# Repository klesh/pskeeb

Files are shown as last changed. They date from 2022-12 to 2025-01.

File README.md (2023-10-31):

# Portable Split Keyboard

## Features

- Tenting design - good for RSI symptoms
- Stackable - portable
- 36 keys columnar layout - less movement when typing
- Trackpoint support

## Designs

- [pskeeb1 gateron ks27](pskeeb1_gateron_ks27): Mainly designed for Gateron KS27 low profile switches, Blackpill controller, Diodeless
- [pskeeb2 express](pskeeb2_express): All Kinds of switches, Blackpill controller, Diodeless, 9.2x9.2cm PCB
- [pskeeb3 cherry hotswap](pskeeb3_cherry_hotswap): Cherry MX Switch, Raspberry Pi Pico, Diodeless

## Assembly

#### Trackpoint

1. Follow [this great guide](https://github.com/alonswartz/trackpoint#q-how-do-i-identify-the-trackpoint-pinout) and [this topic](https://geekhack.org/index.php?topic=115912.0) to identify the trackpoint pinout
2. Solder GH cable to the trackpoint by refering to the socket wiring sequence: RST/DAT/CLK/GND/VCC (top to bottom)

## Developement

```
git clone https://github.com/klesh/pskeeb.git
git submodule update --init --recursive
```

Use the following options when exporting gerber for JLCPCB manufactoring.
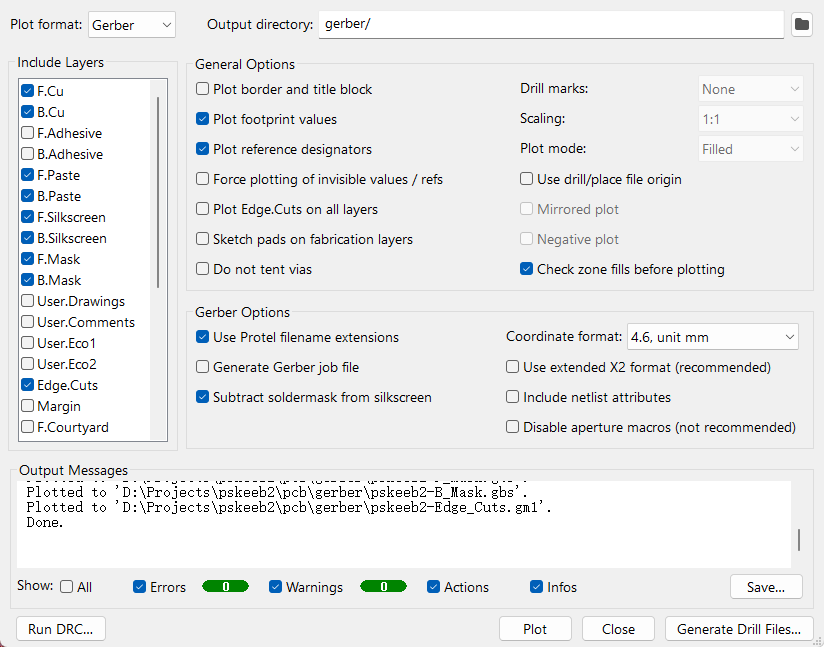
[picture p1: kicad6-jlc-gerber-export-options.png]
gerber options for jlcpcb


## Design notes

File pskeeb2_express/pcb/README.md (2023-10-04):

# Preview

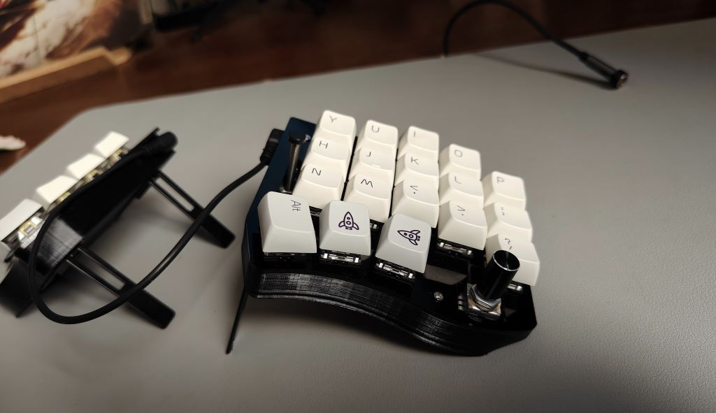
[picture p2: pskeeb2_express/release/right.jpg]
pskeeb2.5 cherry mx switch - right

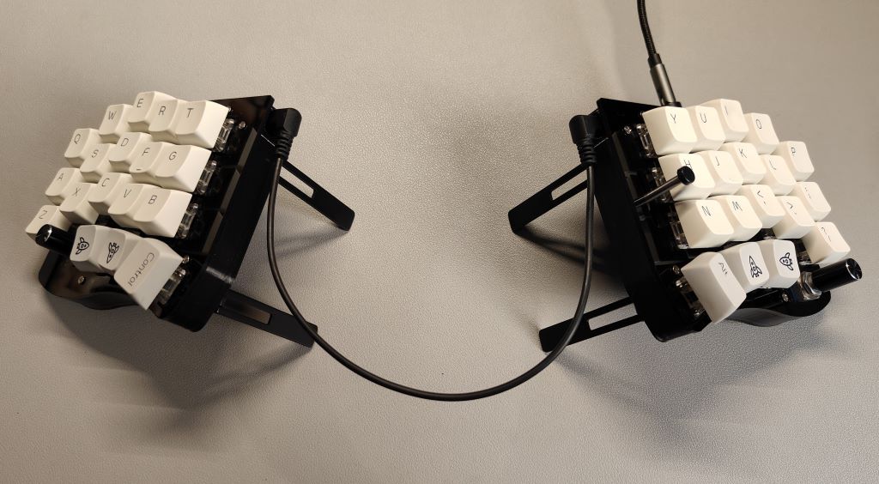
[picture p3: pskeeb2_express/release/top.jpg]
pskeeb2.5 cherry mx switch - top

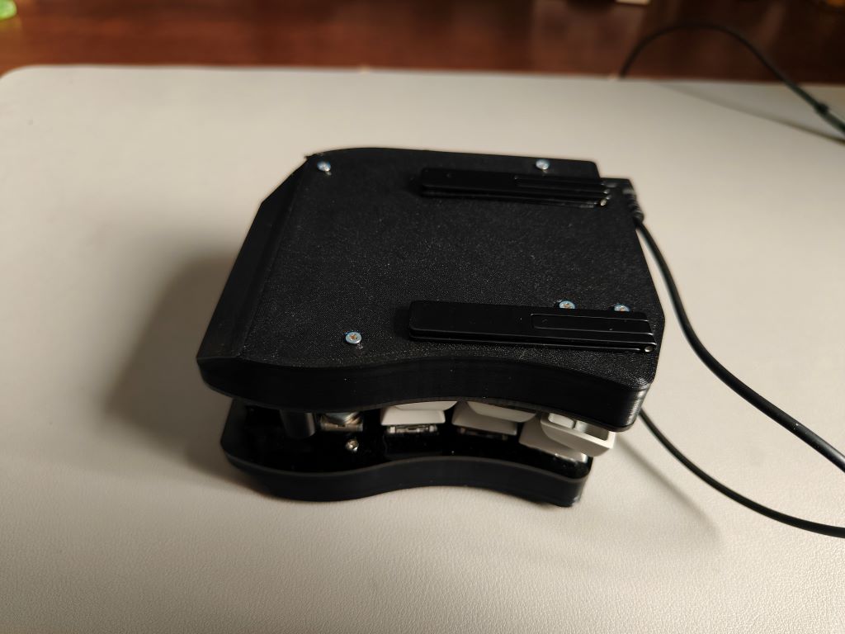
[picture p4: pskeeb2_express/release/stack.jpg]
pskeeb2.5 cherry mx switch - stack


# BOM

- [Laser cut acrylic top plate](ak-bp/release/pskeeb2.5-topplate.dxf)
- [3D printed case](ak-bp/release/pskeeb2.5-case.stl) x 2pcs (one of them must be mirrored in your slicing software)
- Blackpill stm32f401 x 2pcs
- m2x5 screw x 24pcs for plates and cases
- PJ-320A TRRS headphone jack x 2pcs / 3.5mm TRRS cabck 4 Pole x 1pc
- m2x7 screw and m2x1(thickness) washer x 2pcs each for mouting trackpoint
- GH 1.25mm Pitch 1x05 pins and cable x 1pc for trackpoint connection
- m2x13mm female-to-female brass standoff x 12pcs
- 2.2uF Capcitor x 1pc / 100k Resistor x 1pc / 4.7k Resistor x 2pcs for trackpoint reset circuit
- 3.5(outer)x0.2(thickness)x3.1mm(inner) stainless steel tube x 1pc / Silicon rubber cap for trackpoint extending x 1pc
- Thin phone stand x 2pc
- MX Switches x 36pcs / keycaps x 36pcs
- EC11 rotary encoder and knob x 2pcs
- Optional 2.54mm pitch single row socket with 3.5mm profile x 2pcs for mounting MicroController

# Fireware and keymap

1. [Download the firmware](https://github.com/klesh/pskeeb2/releases/download/v2.5/pskeeb2_vial.bin) and follow the [QMK doc](https://docs.qmk.fm/#/newbs_flashing) to flash the Blackpills
2. [Download the vial](https://get.vial.today/download/) and use it to configure your keymap

# Trackpoint

1. Follow [this great guide](https://github.com/alonswartz/trackpoint#q-how-do-i-identify-the-trackpoint-pinout) and [this topic](https://geekhack.org/index.php?topic=115912.0) to identify the trackpoint pinout
2. Solder GH cable to the trackpoint by refering to the socket wiring sequence: RST/DAT/CLK/GND/VCC (top to bottom)

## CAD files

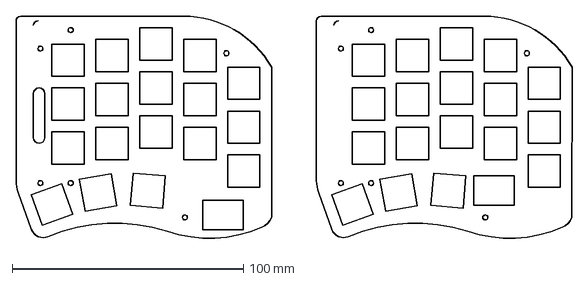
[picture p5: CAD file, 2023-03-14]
pskeeb2_express/release/pskeeb2.5-topplate.dxf
240.6 x 97.5 mm

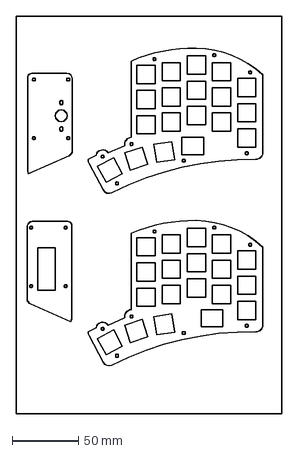
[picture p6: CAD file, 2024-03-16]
pskeeb3_cherry_hotswap/release/plates/top-plate-200x300x2mm-blk.dxf
200.0 x 300.0 mm

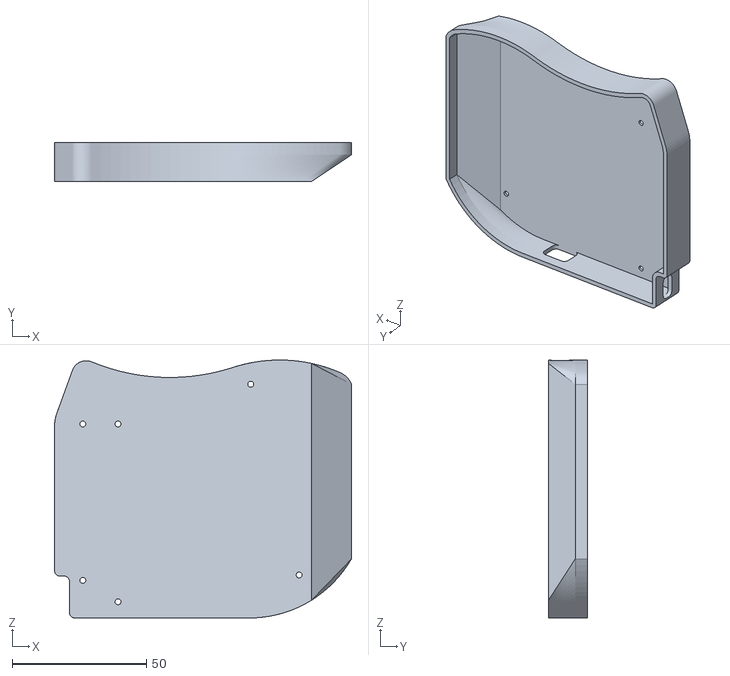
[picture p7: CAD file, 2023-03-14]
pskeeb2_express/release/pskeeb2.5-case.stl
110.6 x 14.6 x 96.0

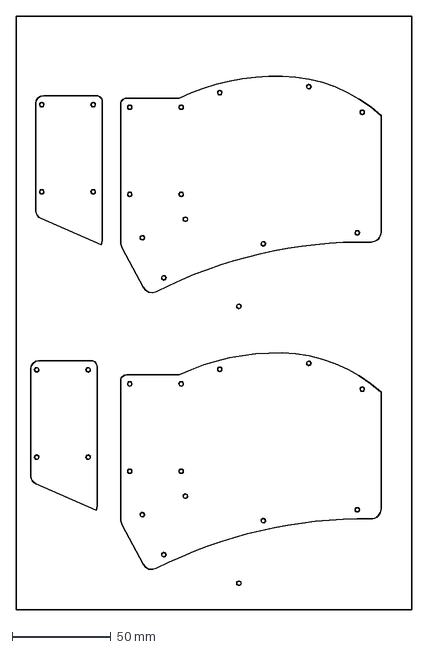
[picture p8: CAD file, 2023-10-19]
pskeeb3_cherry_hotswap/release/plates/bottom-plate-200x300x1mm-transparent.dxf
200.0 x 300.0 mm

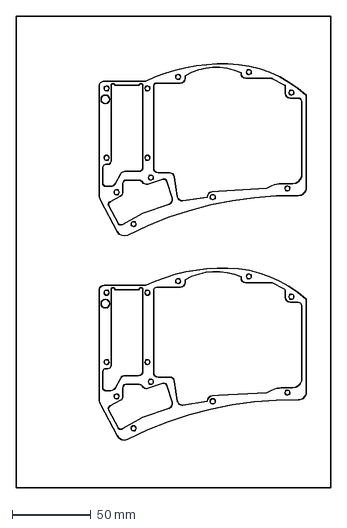
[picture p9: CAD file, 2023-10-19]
pskeeb3_cherry_hotswap/release/plates/bottom-spacer-200x300x2mm-transparent.dxf
200.0 x 300.0 mm

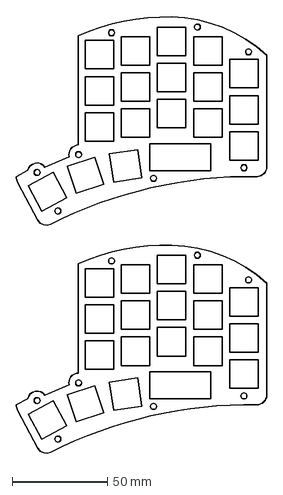
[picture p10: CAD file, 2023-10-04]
pskeeb3_cherry_hotswap/release/plates/top-spacer-200x300x3mm-blk.dxf
131.7 x 230.6 mm

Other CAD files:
pskeeb1_gateron_ks27/plates/plates-shield-cutting.FCStd

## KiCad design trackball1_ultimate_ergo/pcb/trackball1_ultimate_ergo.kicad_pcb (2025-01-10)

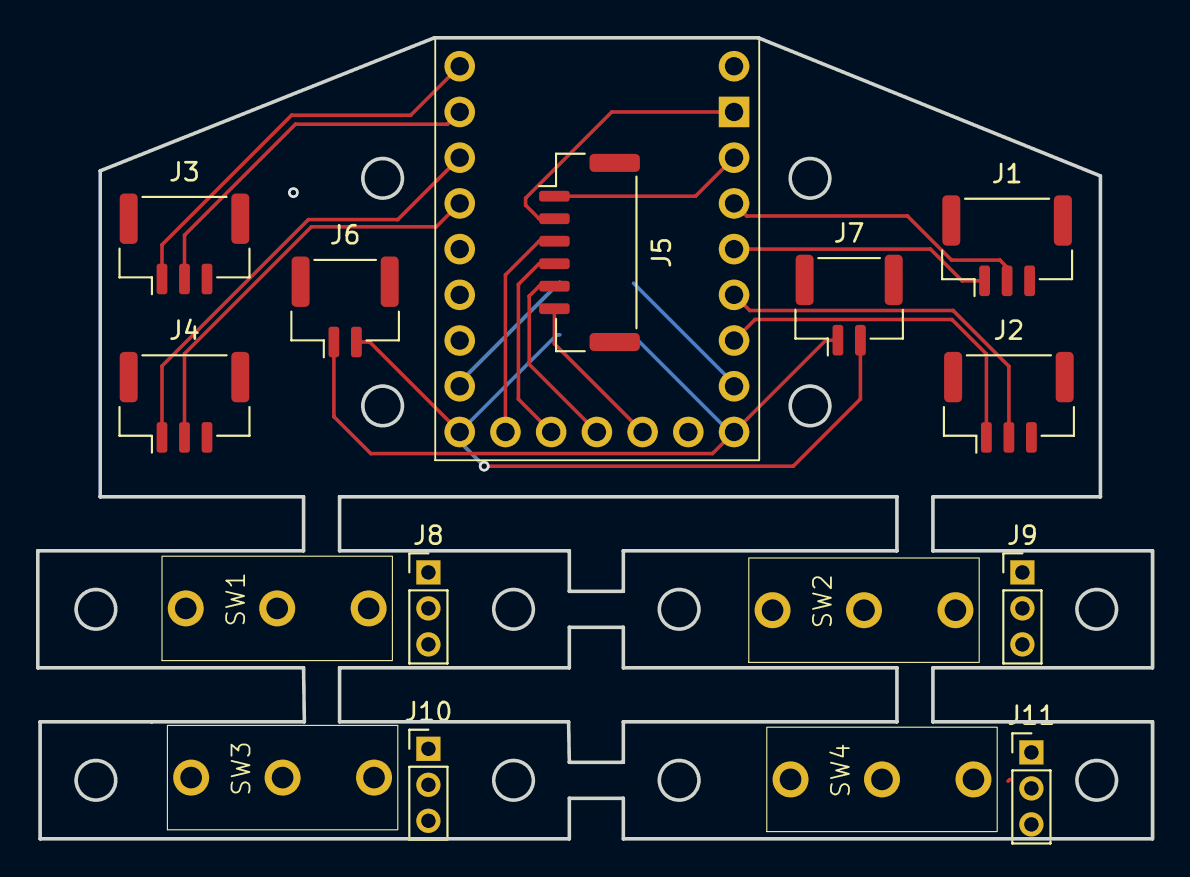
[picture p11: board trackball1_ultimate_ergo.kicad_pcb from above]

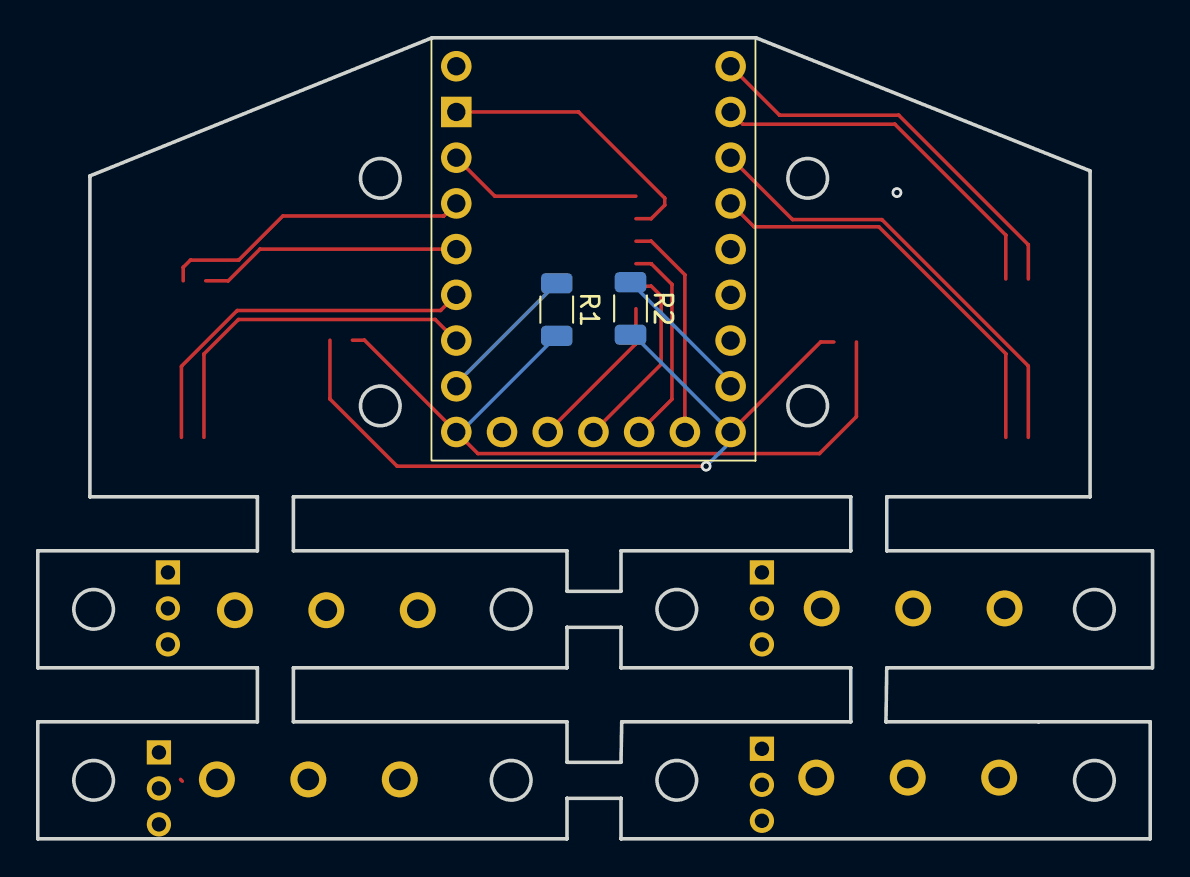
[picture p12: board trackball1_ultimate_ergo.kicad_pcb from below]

Board: 2 copper layers, 61.9 x 44.5 mm, 18 parts (3 on the bottom side), 30 nets.

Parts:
J1, J2, J3, J4: Conn_01x03; JST_GH_BM03B-GHS-TBT_1x03-1MP_P1.25mm_Vertical
J5: Conn_01x06; JST_GH_BM06B-GHS-TBT_1x06-1MP_P1.25mm_Vertical
J6, J7: Conn_01x02; JST_GH_BM02B-GHS-TBT_1x02-1MP_P1.25mm_Vertical
J8, J9, J10, J11: Conn_01x03; PinHeader_1x03_P2.00mm_Vertical
R1, R2: 100k; R_1206_3216Metric
SW1, SW2, SW3, SW4: SW_SPDT_312; MouseSwitch
U1: RP2024-Zero

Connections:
GND: J1.2, J2.2, J3.2, J4.2, J5.2, U1.2 (GND)
MOTION: J5.6, U1.11 (GP12)
unnamed: J8.1, SW1.1 (B)
unnamed: J8.2, SW1.2 (C)
unnamed: J8.3, SW1.3 (A)
unnamed: J9.1, SW2.1 (B)
unnamed: J9.2, SW2.2 (C)
unnamed: J9.3, SW2.3 (A)
unnamed: J10.1, SW3.1 (B)
unnamed: J10.2, SW3.2 (C)
unnamed: J10.3, SW3.3 (A)
unnamed: J11.1, SW4.1 (B)
unnamed: J11.2, SW4.2 (C)
unnamed: J11.3, SW4.3 (A)
SCLK: J5.5, U1.12 (GP11)
SDIO: J5.4, U1.13 (GP10)
VIN: J5.1, U1.3 (3V3)
btn1: J1.3, U1.4 (GP29)
btn1c: J1.1, U1.5 (GP28)
btn2: J2.3, U1.6 (GP27)
btn2c: J2.1, U1.7 (GP26)
btn3: J3.3, U1.22 (GP1)
btn3c: J3.1, U1.23 (GP0)
btn4: J4.3, U1.20 (GP3)
btn4c: J4.1, U1.21 (GP2)
nCS: J5.3, U1.14 (GP9)
touch1_in: J6.1, J7.1, R1.2, U1.9 (GP14)
touch1_out: R1.1, U1.8 (GP15)
touch2_in: J6.2, J7.2, R2.2, U1.15 (GP8)
touch2_out: R2.1, U1.16 (GP7)

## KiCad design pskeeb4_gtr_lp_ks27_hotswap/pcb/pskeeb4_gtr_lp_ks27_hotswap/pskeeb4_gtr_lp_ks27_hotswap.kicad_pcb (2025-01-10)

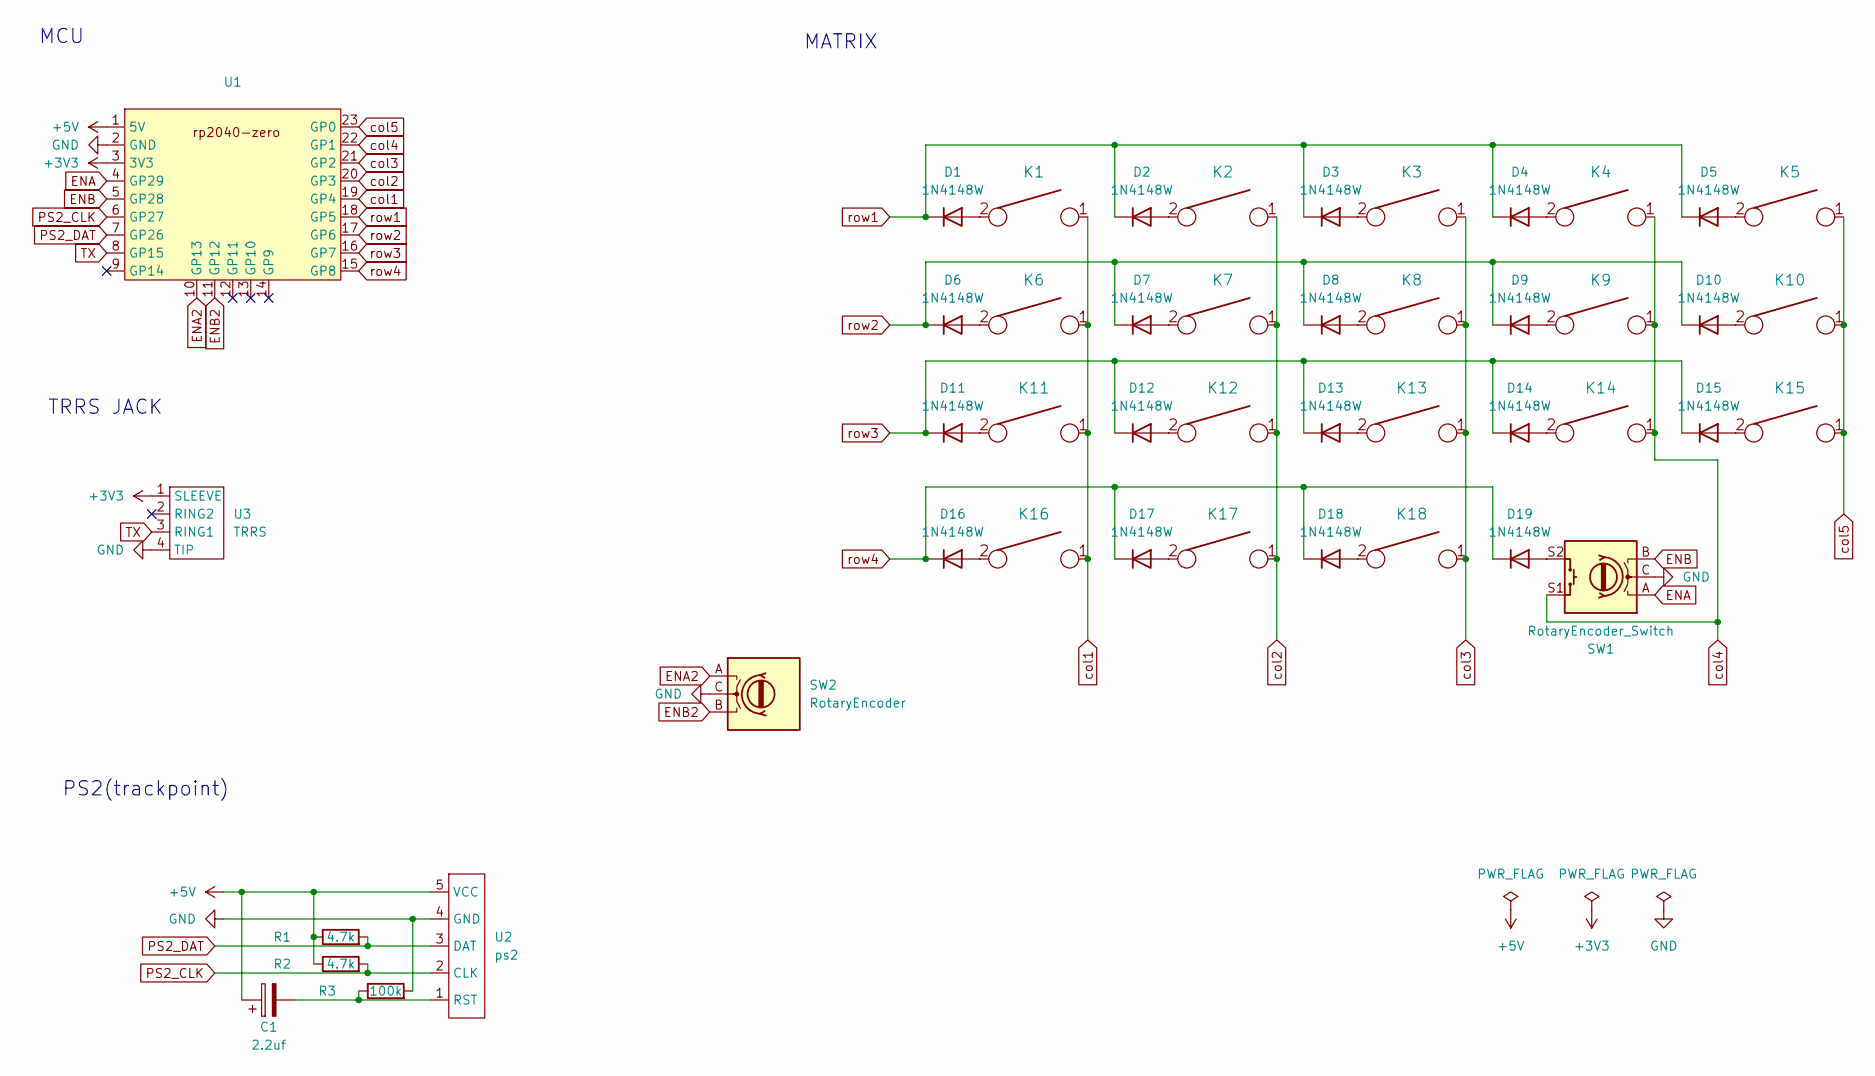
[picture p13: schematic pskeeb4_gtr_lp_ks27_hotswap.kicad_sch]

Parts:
C1: 2.2uf; C_1206_3216Metric_Pad1.33x1.80mm_HandSolder
D1, D2, D3, D4, D5, D6, D7, D8, D9, D10, D11, D12, D13, D14, D15, D16, D17, D18, D19: 1N4148W; D_SOD-123 Reversible
K1, K2, K3, K4, K5, K6, K7, K8, K9, K10, K11, K12, K13, K14, K15, K16, K17, K18: KEYSW; Gateron KS-27 Hotswap Reversible
R1, R2: 4.7k; C_1206_3216Metric_Pad1.33x1.80mm_HandSolder
R3: 100k; C_1206_3216Metric_Pad1.33x1.80mm_HandSolder
SW1: RotaryEncoder_Switch; E8H8 Rotary Encoder Reversible
SW2: RotaryEncoder; nobole-rotary-encoder
U1: RP2024-Zero
U2: ps2; JST_GH_BM05B-GHS-TBT_1x05-1MP_P1.25mm_Vertical
U3: TRRS; TRRS-PJ-320D Reversible

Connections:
+3V3: U1.3 (3V3), U3.1 (SLEEVE)
+5V: C1.1, R1.1, R2.1, U1.1 (5V), U2.5 (VCC)
ENA: SW1.A, U1.4 (GP29)
ENA2: SW2.A, U1.10 (GP13)
ENB: SW1.B, U1.5 (GP28)
ENB2: SW2.B, U1.11 (GP12)
GND: R3.2, SW1.C, SW2.C, U1.2 (GND), U2.4 (GND), U3.4 (TIP)
unnamed: D1.2 (A), K1.2
unnamed: D2.2 (A), K2.2
unnamed: D3.2 (A), K3.2
unnamed: D4.2 (A), K4.2
unnamed: D5.2 (A), K5.2
unnamed: D6.2 (A), K6.2
unnamed: D7.2 (A), K7.2
unnamed: D8.2 (A), K8.2
unnamed: D9.2 (A), K9.2
unnamed: D10.2 (A), K10.2
unnamed: D11.2 (A), K11.2
unnamed: D12.2 (A), K12.2
unnamed: D13.2 (A), K13.2
unnamed: D14.2 (A), K14.2
unnamed: D15.2 (A), K15.2
unnamed: D16.2 (A), K16.2
unnamed: D17.2 (A), K17.2
unnamed: D18.2 (A), K18.2
unnamed: D19.2 (A), SW1.S2
unnamed: C1.2, R3.1, U2.1 (RST)
PS2_CLK: R2.2, U1.6 (GP27), U2.2 (CLK)
PS2_DAT: R1.2, U1.7 (GP26), U2.3 (DAT)
TX: U1.8 (GP15), U3.3 (RING1)
col1: K1.1, K6.1, K11.1, K16.1, U1.19 (GP4)
col2: K2.1, K7.1, K12.1, K17.1, U1.20 (GP3)
col3: K3.1, K8.1, K13.1, K18.1, U1.21 (GP2)
col4: K4.1, K9.1, K14.1, SW1.S1, U1.22 (GP1)
col5: K5.1, K10.1, K15.1, U1.23 (GP0)
row1: D1.1 (K), D2.1 (K), D3.1 (K), D4.1 (K), D5.1 (K), U1.18 (GP5)
row2: D6.1 (K), D7.1 (K), D8.1 (K), D9.1 (K), D10.1 (K), U1.17 (GP6)
row3: D11.1 (K), D12.1 (K), D13.1 (K), D14.1 (K), D15.1 (K), U1.16 (GP7)
row4: D16.1 (K), D17.1 (K), D18.1 (K), D19.1 (K), U1.15 (GP8)

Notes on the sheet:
MATRIX
MCU
TRRS JACK
PS2(trackpoint)

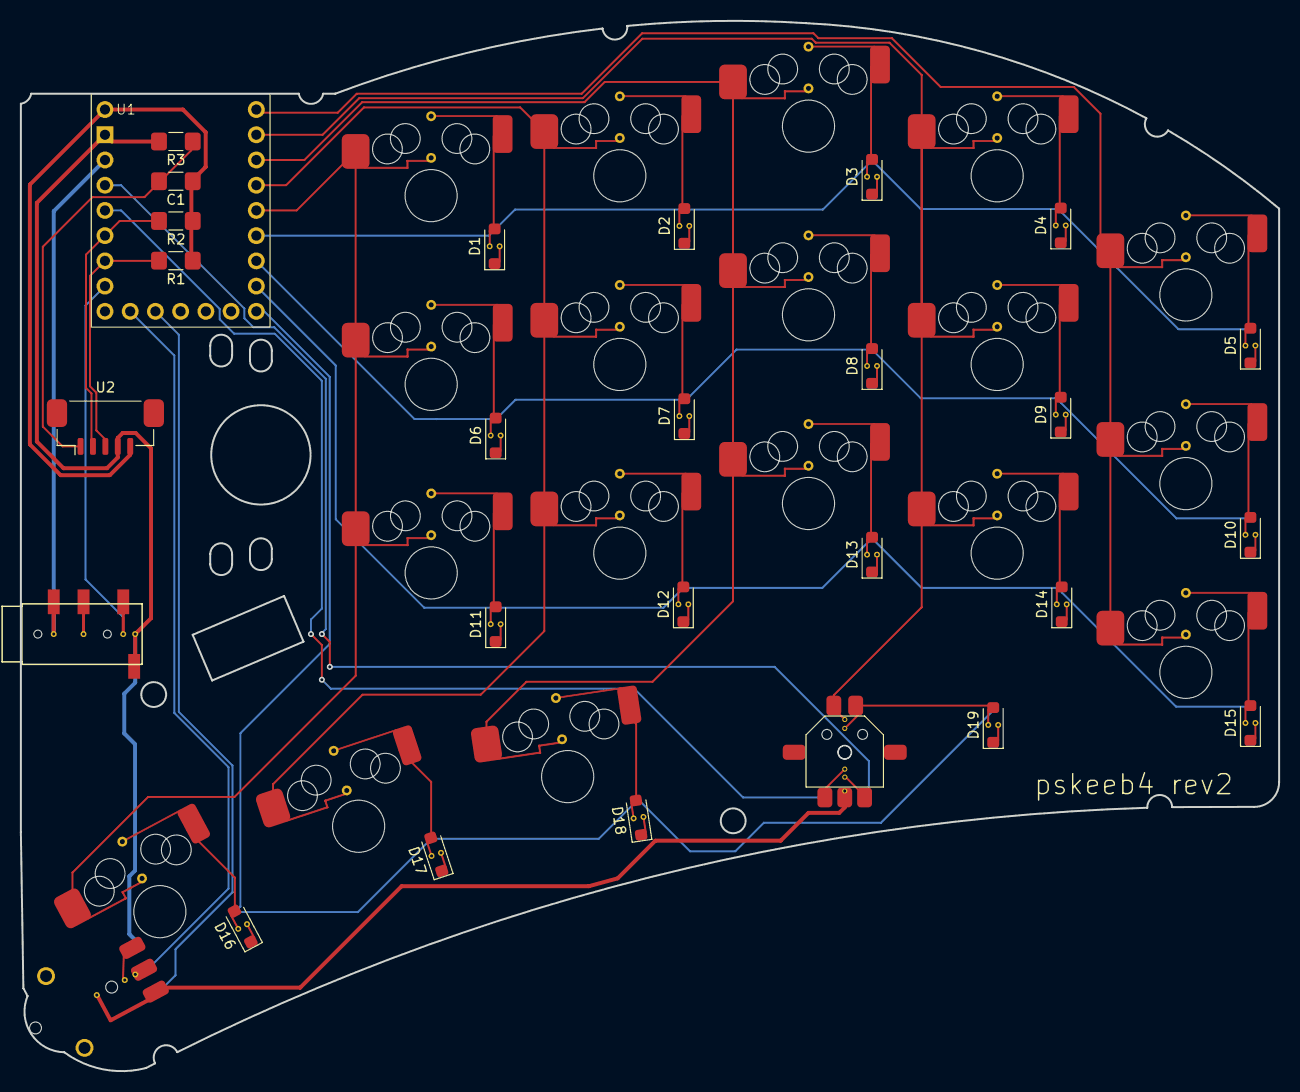
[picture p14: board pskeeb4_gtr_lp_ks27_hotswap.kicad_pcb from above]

Board: 2 copper layers, 126.7 x 105.8 mm, 46 parts (0 on the bottom side), 39 nets.

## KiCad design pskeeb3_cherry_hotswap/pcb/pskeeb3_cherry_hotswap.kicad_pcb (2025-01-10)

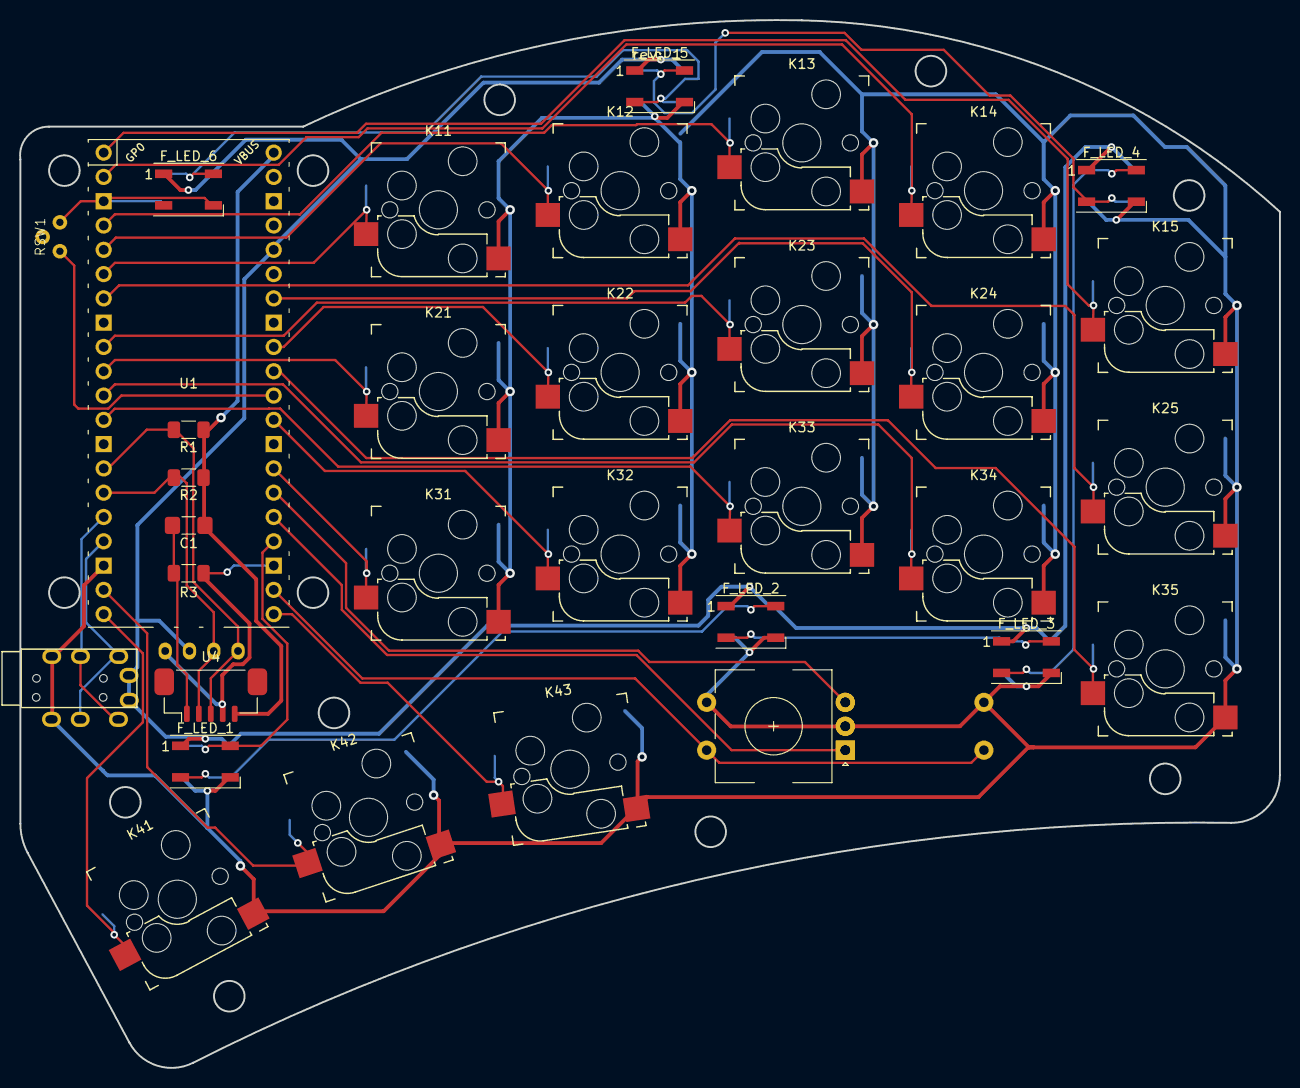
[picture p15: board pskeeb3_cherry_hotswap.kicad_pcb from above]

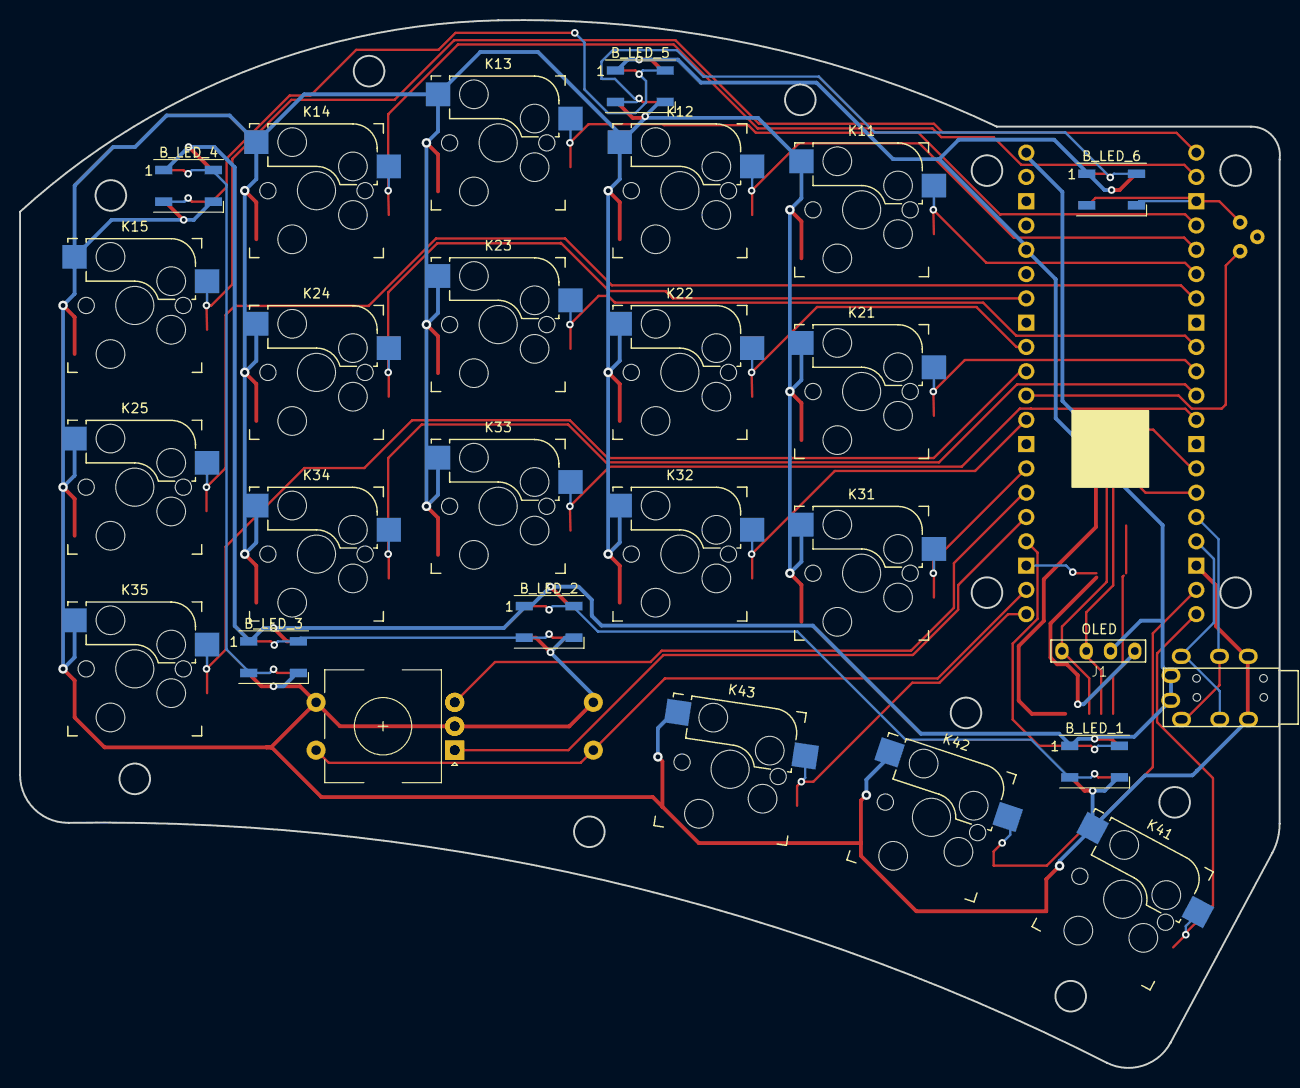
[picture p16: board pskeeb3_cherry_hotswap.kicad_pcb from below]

Board: 2 copper layers, 131.7 x 109.6 mm, 42 parts (9 on the bottom side), 38 nets.

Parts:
B_LED_1, B_LED_2, B_LED_3, B_LED_4, B_LED_5, B_LED_6: WS2812B; LED_WS2812B_PLCC4_5.0x5.0mm_P3.2mm
C1: 2.2uf; C_1206_3216Metric_Pad1.33x1.80mm_HandSolder
F_LED_1, F_LED_2, F_LED_3, F_LED_4, F_LED_5, F_LED_6: WS2812B; LED_WS2812B_PLCC4_5.0x5.0mm_P3.2mm
J1: OLED
K11, K12, K13, K14, K15, K21, K22, K23, K24, K25, K31, K32, K33, K34, K35, K41, K42, K43: KEYSW; Kailh_socket_MX_reversible
R1, R2: 4.7k; R_1206_3216Metric_Pad1.30x1.75mm_HandSolder
R3: 100k; R_1206_3216Metric_Pad1.30x1.75mm_HandSolder
RSW1: SW_PUSH; 4.5x4.5x5side-switch
SW1, SW2: RotaryEncoder_Switch; RotaryEncoder_EC11-no-legs
U1: Pico; RPi_Pico_TH
U2, U3: TRRS; TRRS-PJ-320A
U4: trackpoint; JST_GH_BM05B-GHS-TBT_1x05-1MP_P1.25mm_Vertical

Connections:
+3V3: B_LED_1.1 (VDD), B_LED_2.1 (VDD), B_LED_3.1 (VDD), B_LED_4.1 (VDD), B_LED_5.1 (VDD), B_LED_6.1 (VDD), F_LED_1.1 (VDD), F_LED_2.1 (VDD), F_LED_3.1 (VDD), F_LED_4.1 (VDD), F_LED_5.1 (VDD), F_LED_6.1 (VDD), J1.3, U1.36 (3V3), U2.1 (SLEEVE), U3.1 (SLEEVE)
+5V: C1.1, R1.1, R2.1, U1.40 (VBUS), U4.5 (VCC)
/k11: K11.2, U1.6 (GPIO4)
/k12: K12.2, U1.5 (GPIO3)
/k13: K13.2, U1.4 (GPIO2)
/k14: K14.2, U1.2 (GPIO1)
/k15: K15.2, U1.1 (GPIO0)
/k21: K21.2, U1.10 (GPIO7)
/k22: K22.2, U1.32 (GPIO27_ADC1)
/k23: K23.2, U1.9 (GPIO6)
/k24: K24.2, U1.34 (GPIO28_ADC2)
/k25: K25.2, U1.7 (GPIO5)
/k31: K31.2, U1.27 (GPIO21)
/k32: K32.2, U1.29 (GPIO22)
/k33: K33.2, U1.12 (GPIO9)
/k34: K34.2, U1.11 (GPIO8)
/k35: K35.2, U1.31 (GPIO26_ADC0)
/k41: K41.2, U1.20 (GPIO15)
/k42: K42.2, U1.19 (GPIO14)
/k43: K43.2, U1.21 (GPIO16)
/k44: SW1.S2, SW2.S2, U1.22 (GPIO17)
ENA: SW1.A, SW2.A, U1.25 (GPIO19)
ENB: SW1.B, SW2.B, U1.26 (GPIO20)
GND: B_LED_1.3 (VSS), B_LED_2.3 (VSS), B_LED_3.3 (VSS), B_LED_4.3 (VSS), B_LED_5.3 (VSS), F_LED_1.3 (VSS), F_LED_2.3 (VSS), F_LED_3.3 (VSS), F_LED_4.3 (VSS), F_LED_5.3 (VSS), K11.1, K12.1, K13.1, K14.1, K15.1, K21.1, K22.1, K23.1, K24.1, K25.1, K31.1, K32.1, K33.1, K34.1, K35.1, K41.1, K42.1, K43.1, SW1.C, SW1.S1, SW2.C, SW2.S1, U1.18 (GND), U2.4 (TIP), U3.4 (TIP)
GND1: J1.4, R3.2, U1.23 (GND), U4.4 (GND)
GND2: B_LED_6.3 (VSS), F_LED_6.3 (VSS), RSW1.2, U1.3 (GND)
LED: B_LED_1.4 (DIN), F_LED_1.4 (DIN), U1.24 (GPIO18)
unnamed: B_LED_1.2 (DOUT), B_LED_2.4 (DIN), F_LED_1.2 (DOUT), F_LED_2.4 (DIN)
unnamed: B_LED_2.2 (DOUT), B_LED_3.4 (DIN), F_LED_2.2 (DOUT), F_LED_3.4 (DIN)
unnamed: B_LED_3.2 (DOUT), B_LED_4.4 (DIN), F_LED_3.2 (DOUT), F_LED_4.4 (DIN)
unnamed: B_LED_4.2 (DOUT), B_LED_5.4 (DIN), F_LED_4.2 (DOUT), F_LED_5.4 (DIN)
unnamed: B_LED_5.2 (DOUT), B_LED_6.4 (DIN), F_LED_5.2 (DOUT), F_LED_6.4 (DIN)
RX: U1.17 (GPIO13), U2.2 (RING2), U3.3 (RING1)
TP_CLK/I2C1_SCL: J1.2, R2.2, U1.15 (GPIO11), U4.2 (CLK)
TP_DAT/I2C1_SDA: J1.1, R1.2, U1.14 (GPIO10), U4.3 (DAT)
TP_RST: C1.2, R3.1, U4.1 (RST)
TX: U1.16 (GPIO12), U2.3 (RING1), U3.2 (RING2)
run: RSW1.1, U1.30 (RUN)

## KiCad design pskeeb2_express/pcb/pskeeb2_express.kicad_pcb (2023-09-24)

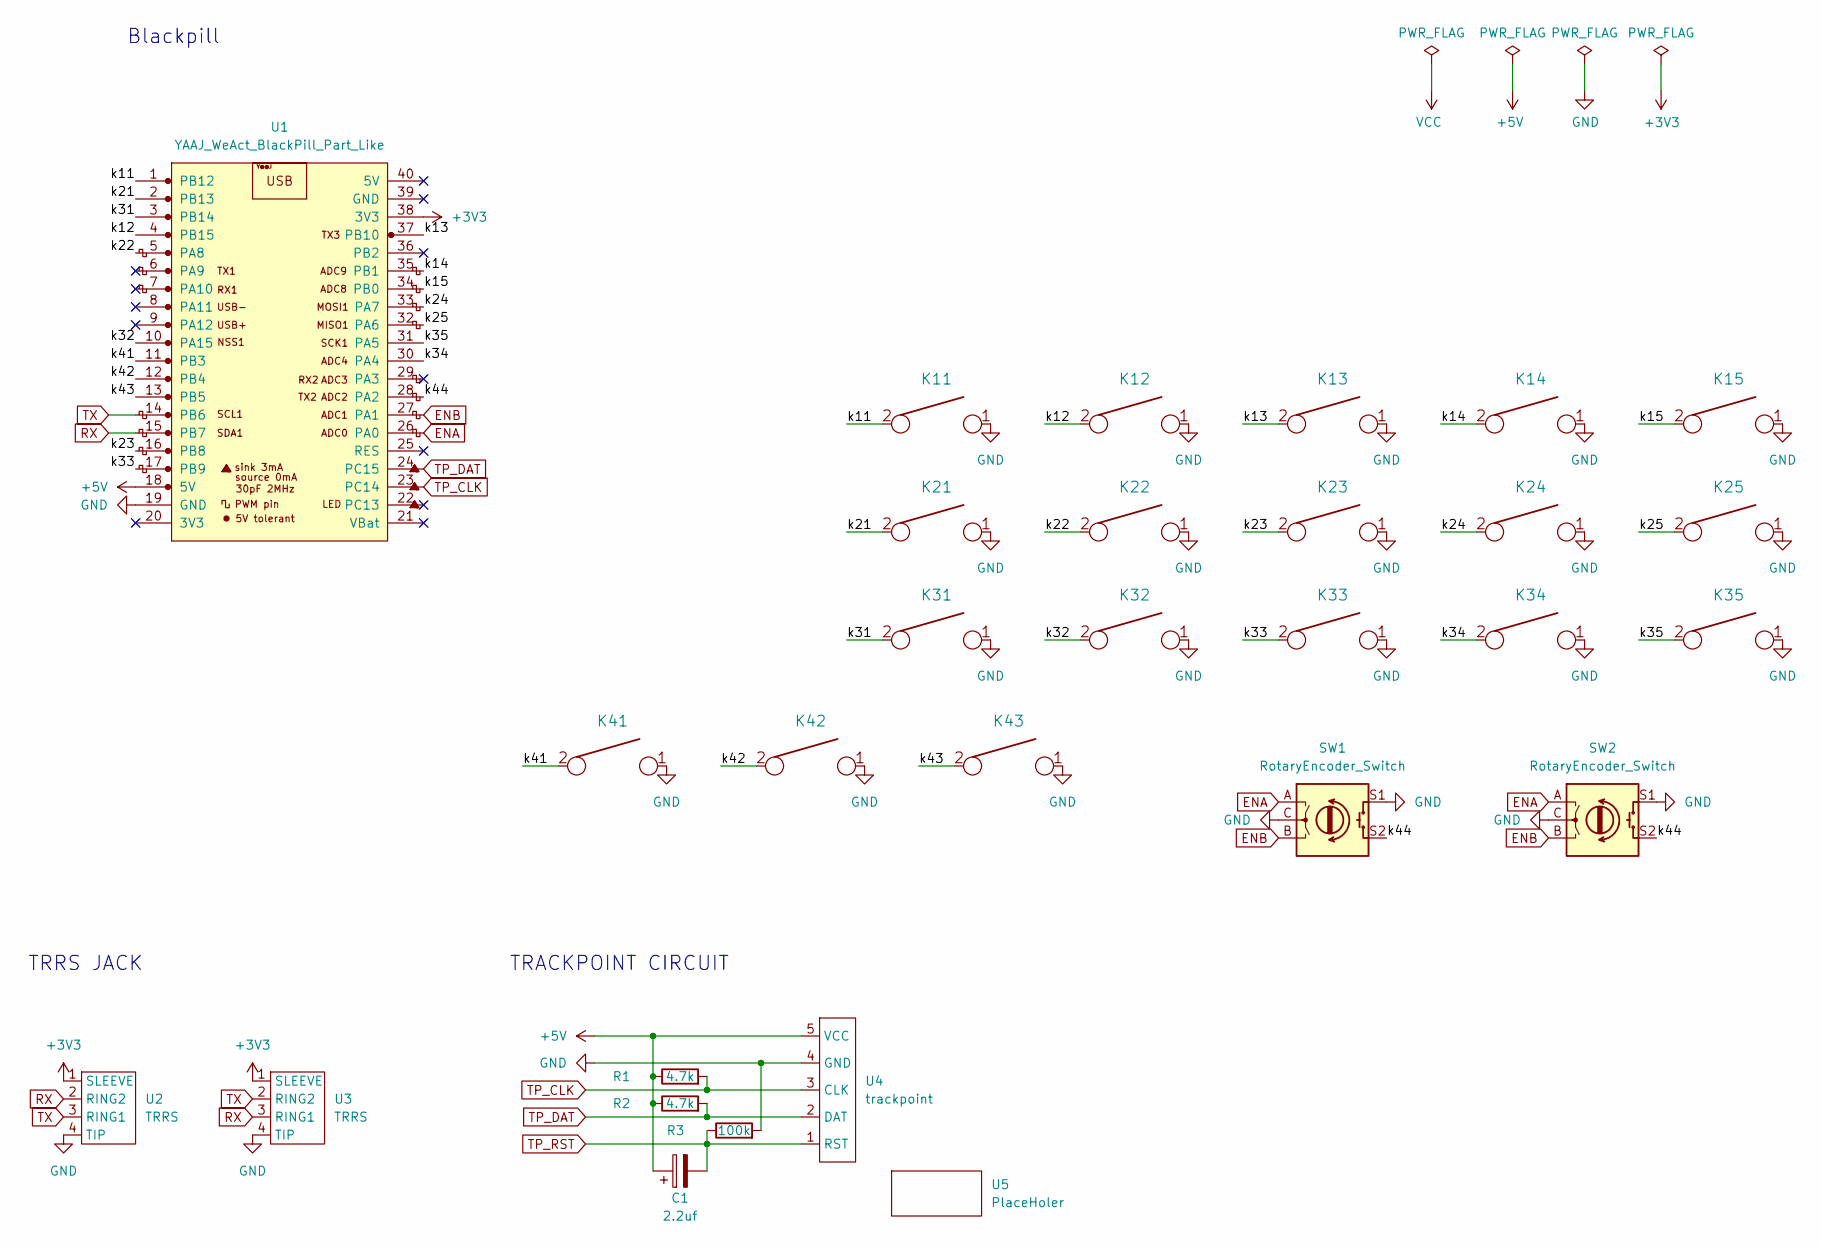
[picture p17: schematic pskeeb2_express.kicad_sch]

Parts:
C1: 2.2uf; C_1206_3216Metric_Pad1.33x1.80mm_HandSolder
K11, K12, K13, K14, K15, K21, K22, K23, K24, K25, K31, K32, K33, K34, K35, K41, K42, K43: KEYSW; Mx-Choc-Rev
R1, R2: 4.7k; R_1206_3216Metric_Pad1.30x1.75mm_HandSolder
R3: 100k; R_1206_3216Metric_Pad1.30x1.75mm_HandSolder
SW1, SW2: RotaryEncoder_Switch; RotaryEncoder_EC11-no-legs
U1: YAAJ_WeAct_BlackPill_Part_Like; YAAJ_WeAct_BlackPill_2
U2, U3: TRRS; TRRS-PJ-320A
U4: trackpoint; JST_GH_SM05B-GHS-TB_1x05-1MP_P1.25mm_Horizontal
U5: PlaceHoler; T400-Trackpoint-mix

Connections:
/k11: K11.2, U1.1 (PB12)
/k12: K12.2, U1.4 (PB15)
/k13: K13.2, U1.37 (PB10)
/k14: K14.2, U1.35 (PB1)
/k15: K15.2, U1.34 (PB0)
/k21: K21.2, U1.2 (PB13)
/k22: K22.2, U1.5 (PA8)
/k23: K23.2, U1.16 (PB8)
/k24: K24.2, U1.33 (PA7)
/k25: K25.2, U1.32 (PA6)
/k31: K31.2, U1.3 (PB14)
/k32: K32.2, U1.10 (PA15)
/k33: K33.2, U1.17 (PB9)
/k34: K34.2, U1.30 (PA4)
/k35: K35.2, U1.31 (PA5)
/k41: K41.2, U1.11 (PB3)
/k42: K42.2, U1.12 (PB4)
/k43: K43.2, U1.13 (PB5)
/k44: SW1.S2, SW2.S2, U1.28 (PA2)
ENA: SW1.A, SW2.A, U1.26 (PA0)
ENB: SW1.B, SW2.B, U1.27 (PA1)
RX: U1.15 (PB7), U2.2 (RING2), U3.3 (RING1)
TP_CLK: R1.2, U1.23 (PC14), U4.3 (CLK)
TP_DAT: R2.2, U1.24 (PC15), U4.2 (DAT)
TP_RST: C1.2, R3.1, U4.1 (RST)
TX: U1.14 (PB6), U2.3 (RING1), U3.2 (RING2)

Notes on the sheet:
TRRS JACK
Blackpill
TRACKPOINT CIRCUIT

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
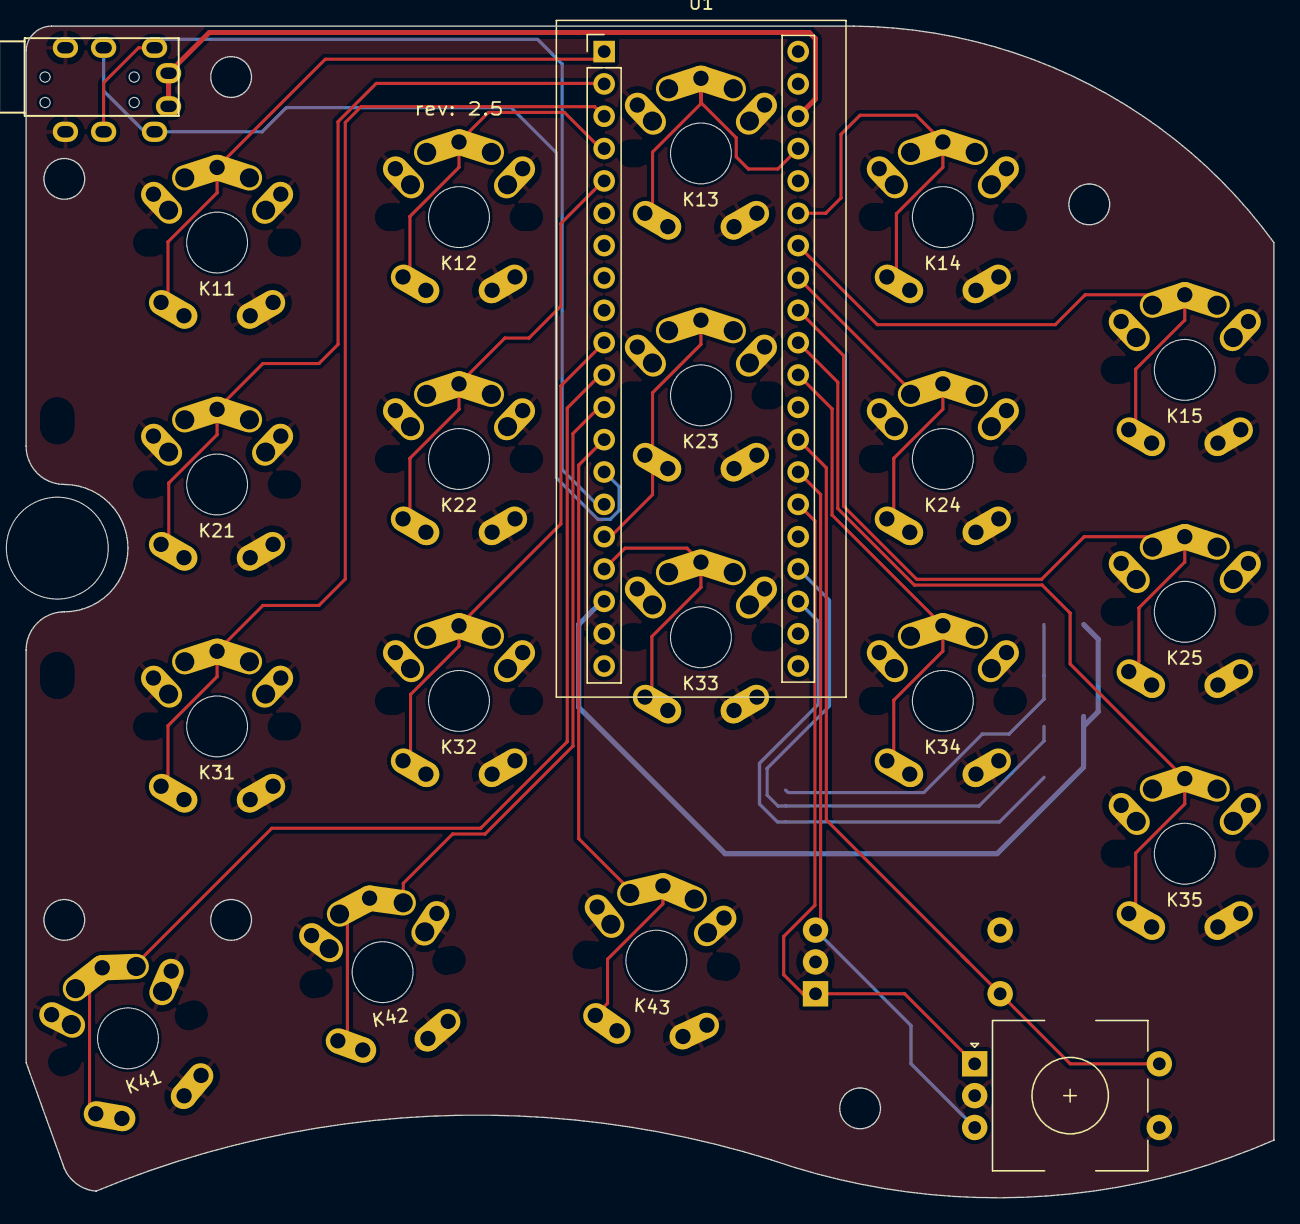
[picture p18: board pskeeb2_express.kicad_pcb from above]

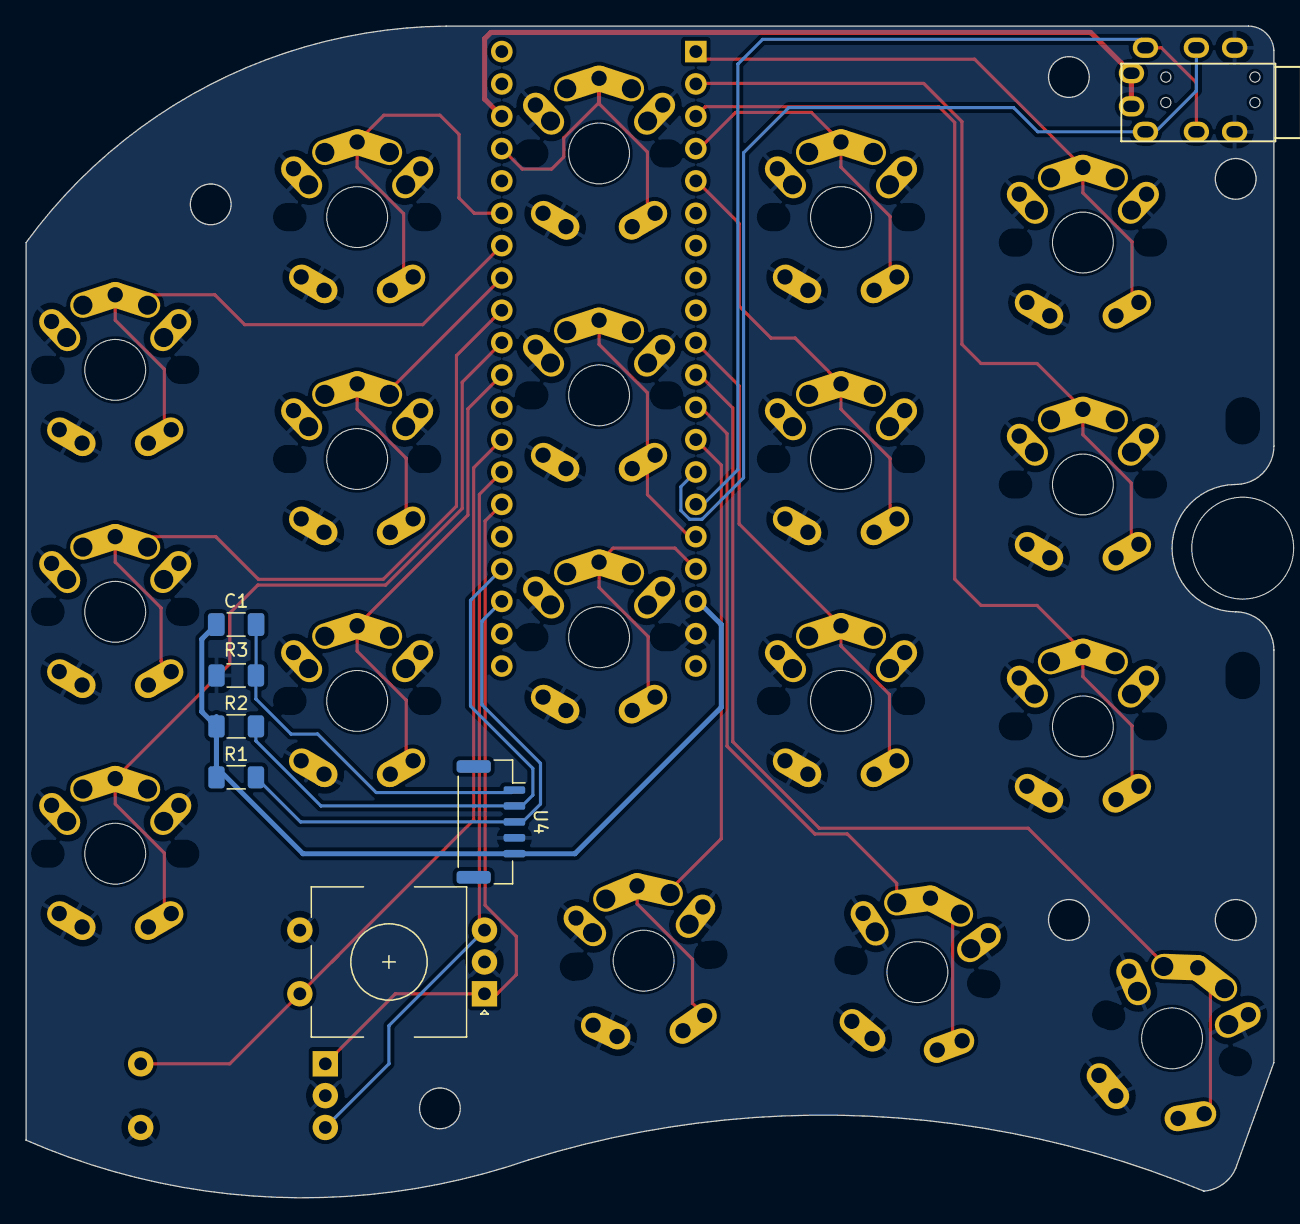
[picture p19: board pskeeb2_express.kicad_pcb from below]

Board: 2 copper layers, 98.0 x 92.0 mm, 29 parts (7 on the bottom side), 29 nets.

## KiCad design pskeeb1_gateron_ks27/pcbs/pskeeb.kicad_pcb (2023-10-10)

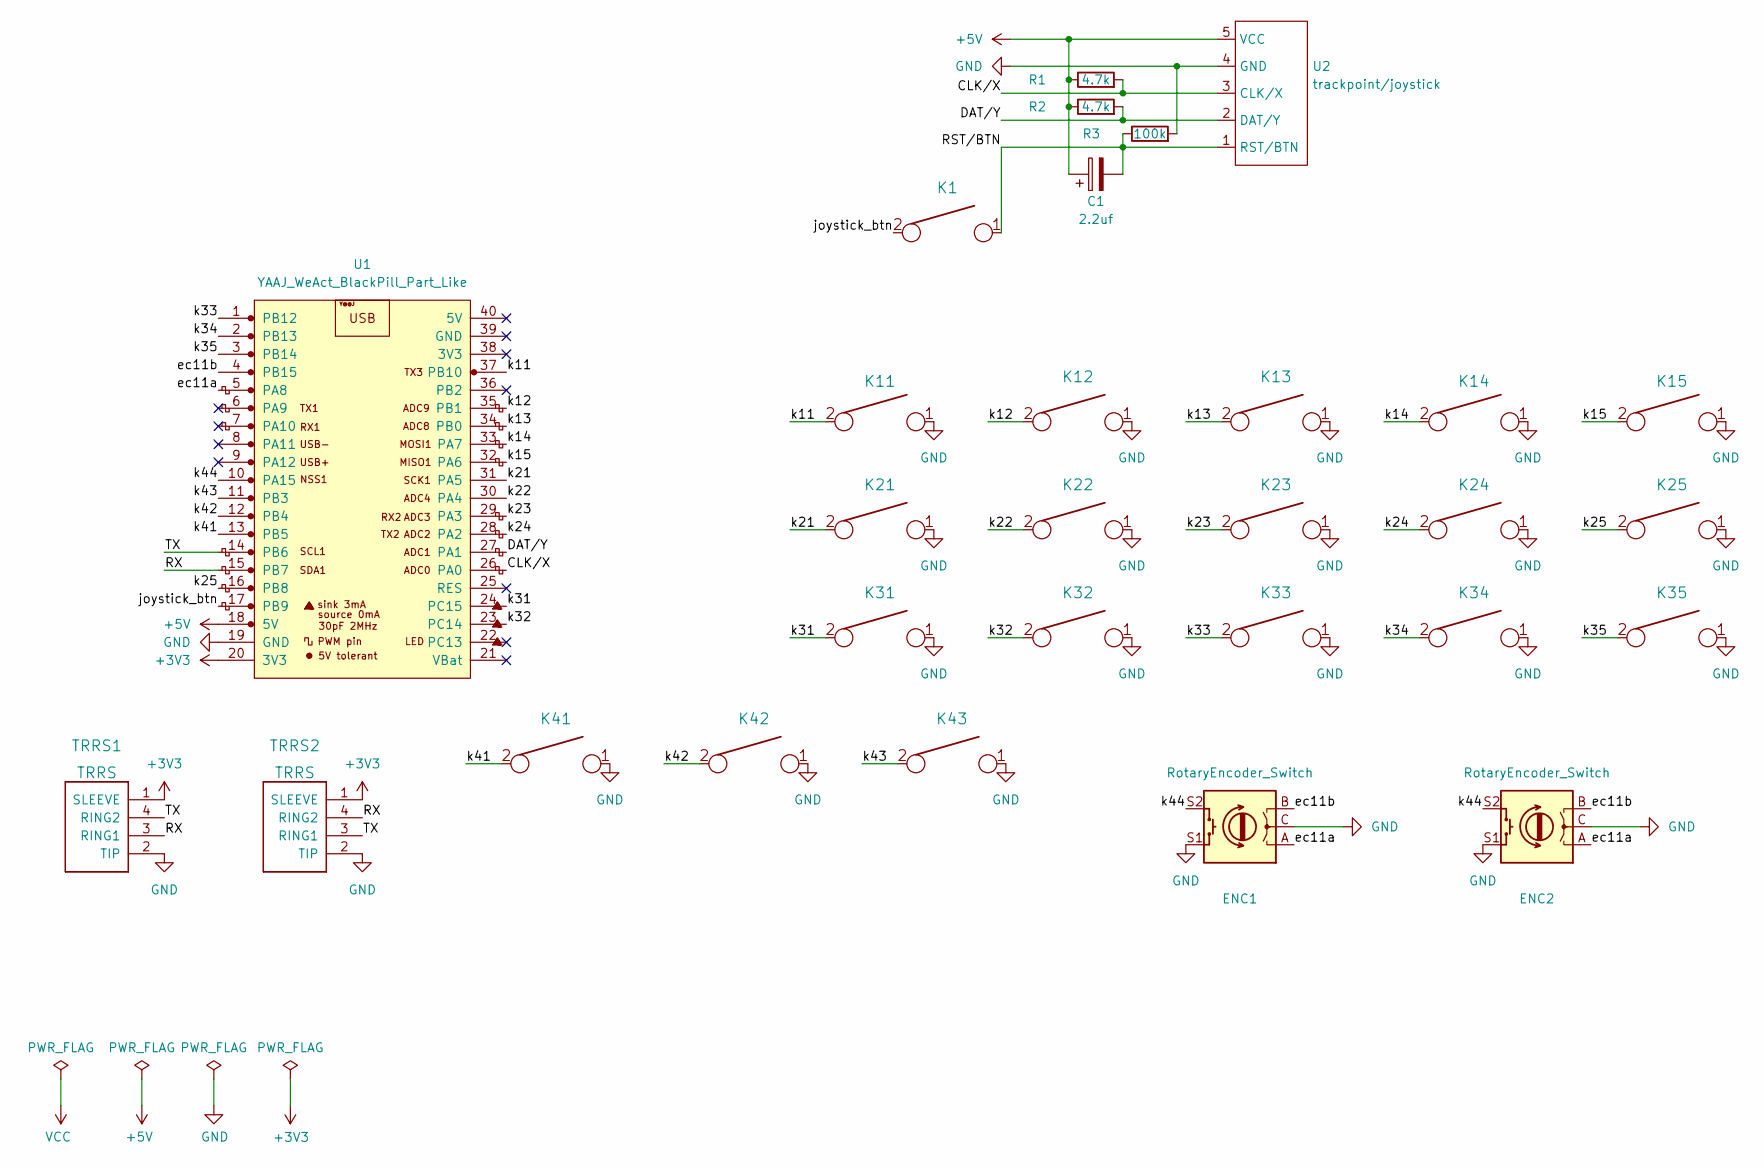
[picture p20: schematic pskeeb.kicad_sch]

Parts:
C1: 2.2uf; CP_Radial_D5.0mm_P2.00mm
ENC1, ENC2: RotaryEncoder_Switch; RotaryEncoder_EC11
K1: KEYSW; R_0201_0603Metric_Pad0.64x0.40mm_HandSolder
K11, K12, K13, K14, K15, K21, K22, K23, K24, K25, K31, K32, K33, K34, K35, K41, K42, K43: KEYSW; Gateron KS-27 Reversible
R1, R2: 4.7k; R_Axial_DIN0207_L6.3mm_D2.5mm_P10.16mm_Horizontal
R3: 100k; R_Axial_DIN0207_L6.3mm_D2.5mm_P10.16mm_Horizontal
TRRS1, TRRS2: TRRS; TRRS-PJ-320A
U1: YAAJ_WeAct_BlackPill_Part_Like; YAAJ_WeAct_BlackPill_2
U2: trackpoint/joystick; JST_GH_BM05B-GHS-TBT_1x05-1MP_P1.25mm_Vertical

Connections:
/CLK/X: R1.2, U1.26 (PA0), U2.3 (CLK/X)
/DAT/Y: R2.2, U1.27 (PA1), U2.2 (DAT/Y)
/RST/BTN: C1.2, K1.1, R3.1, U2.1 (RST/BTN)
/RX: TRRS1.3 (RING1), TRRS2.4 (RING2), U1.15 (PB7)
/TX: TRRS1.4 (RING2), TRRS2.3 (RING1), U1.14 (PB6)
/ec11a: ENC1.A, ENC2.A, U1.5 (PA8)
/ec11b: ENC1.B, ENC2.B, U1.4 (PB15)
/joystick_btn: K1.2, U1.17 (PB9)
/k11: K11.2, U1.37 (PB10)
/k12: K12.2, U1.35 (PB1)
/k13: K13.2, U1.34 (PB0)
/k14: K14.2, U1.33 (PA7)
/k15: K15.2, U1.32 (PA6)
/k21: K21.2, U1.31 (PA5)
/k22: K22.2, U1.30 (PA4)
/k23: K23.2, U1.29 (PA3)
/k24: K24.2, U1.28 (PA2)
/k25: K25.2, U1.16 (PB8)
/k31: K31.2, U1.24 (PC15)
/k32: K32.2, U1.23 (PC14)
/k33: K33.2, U1.1 (PB12)
/k34: K34.2, U1.2 (PB13)
/k35: K35.2, U1.3 (PB14)
/k41: K41.2, U1.13 (PB5)
/k42: K42.2, U1.12 (PB4)
/k43: K43.2, U1.11 (PB3)
/k44: ENC1.S2, ENC2.S2, U1.10 (PA15)

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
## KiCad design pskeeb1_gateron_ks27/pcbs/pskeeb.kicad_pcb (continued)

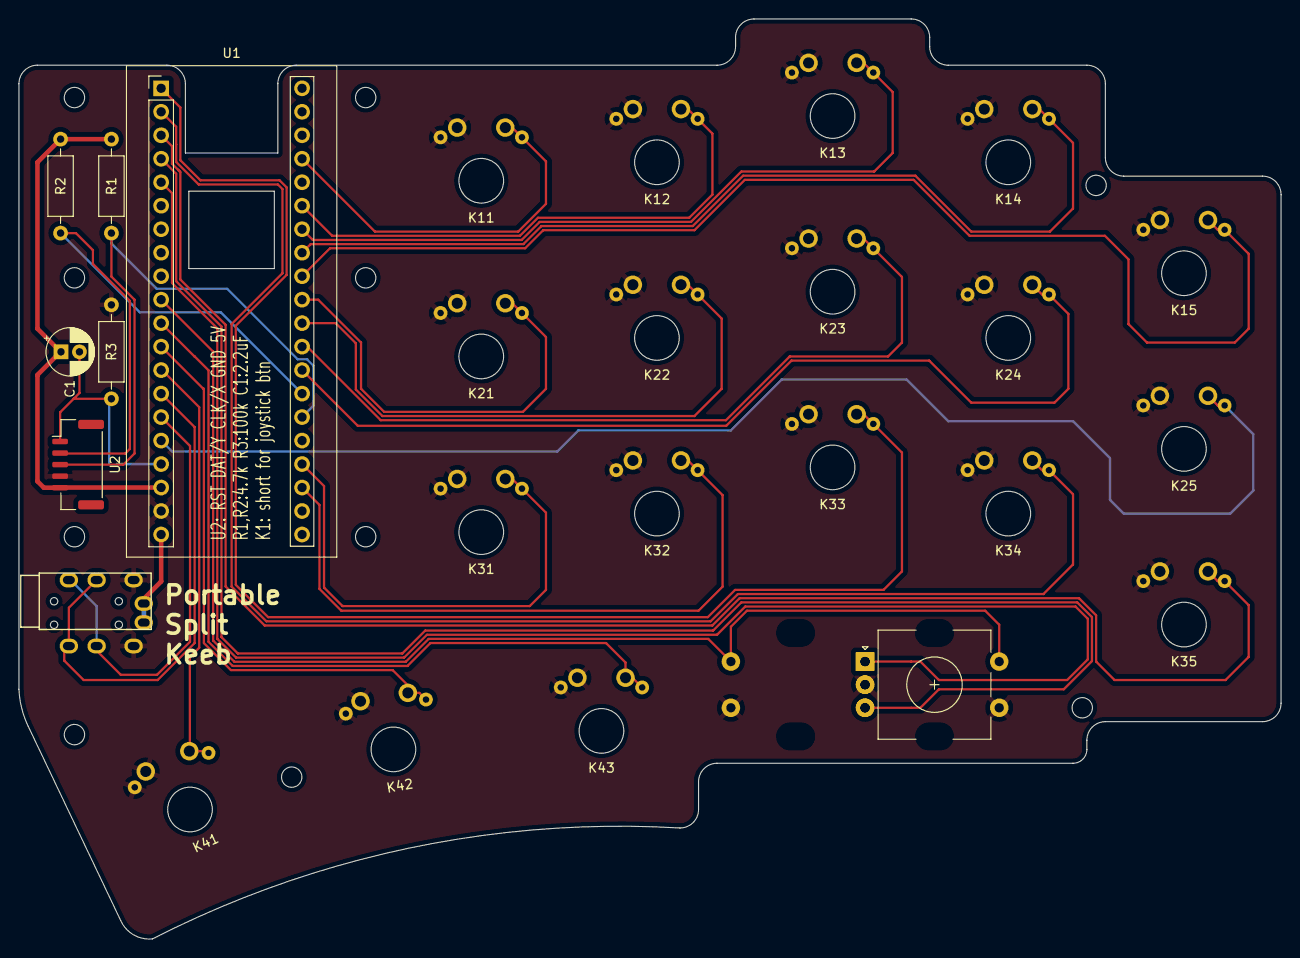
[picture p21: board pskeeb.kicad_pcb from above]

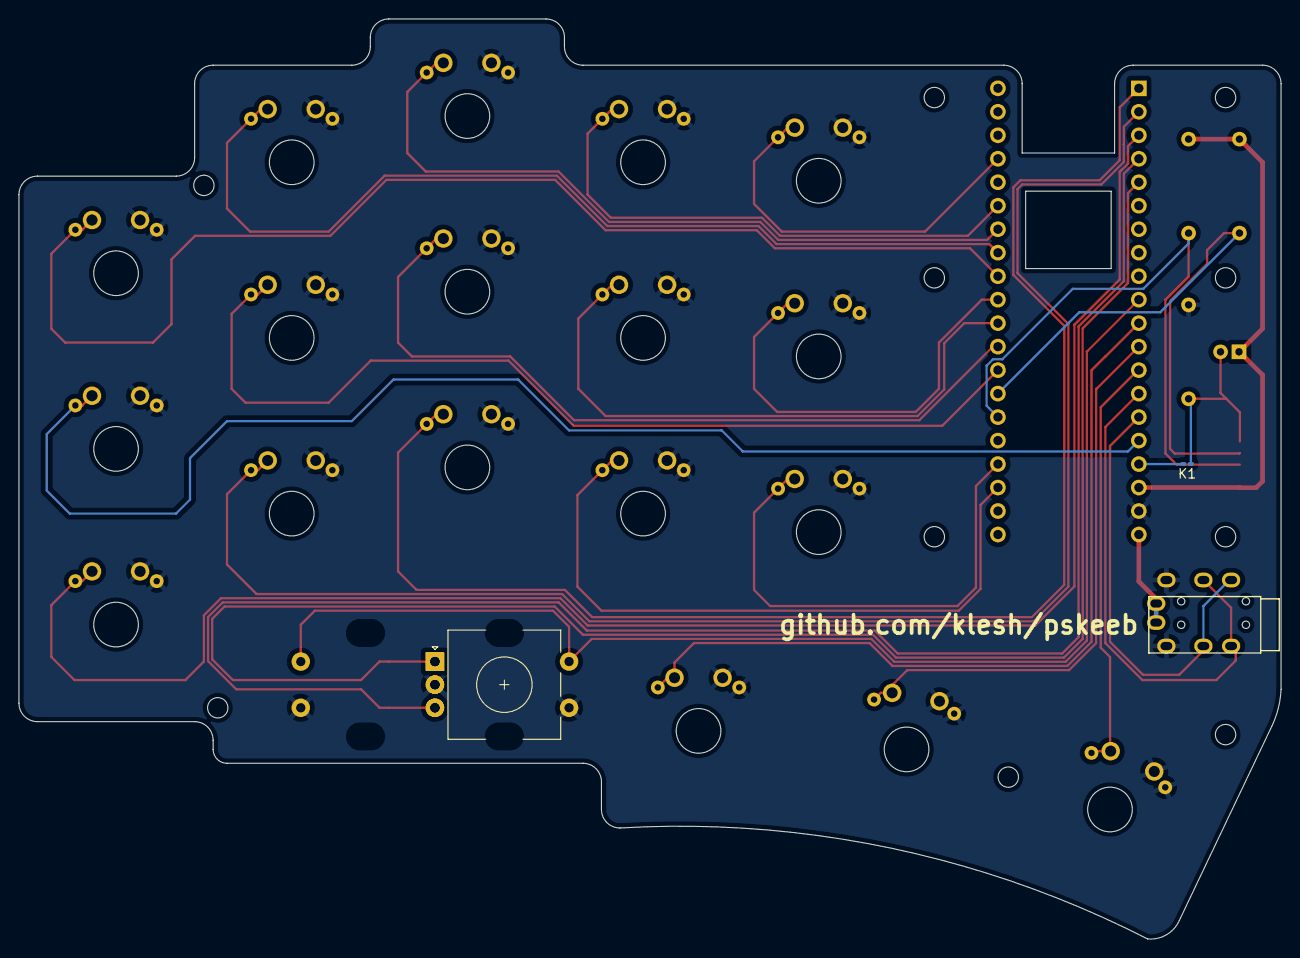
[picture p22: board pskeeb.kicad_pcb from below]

Board: 2 copper layers, 136.5 x 99.5 mm, 29 parts (3 on the bottom side), 30 nets.

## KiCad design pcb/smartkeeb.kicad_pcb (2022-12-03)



Board: 2 copper layers, 98.0 x 94.5 mm, 29 parts (7 on the bottom side), 9 nets, no tracks yet.

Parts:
C1: 2.2uf; C_1206_3216Metric_Pad1.33x1.80mm_HandSolder
J1: OLED; PinHeader_1x04_P2.54mm_Vertical
K11, K12, K13, K14, K15, K21, K22, K23, K24, K25, K31, K32, K33, K34, K35, K41, K42, K43: KEYSW; Gateron Choc Reversible
R1, R2: 4.7k; R_1206_3216Metric_Pad1.30x1.75mm_HandSolder
R3: 100k; R_1206_3216Metric_Pad1.30x1.75mm_HandSolder
SW1, SW2: RotaryEncoder_Switch; RotaryEncoder_Alps_EC11E-Switch_Vertical_H20mm
U1: wemos-esp32-s2-mini; WEMOS_S2_mini
U2, U3: TRRS; TRRS-PJ-320A
U4: trackpoint; PinHeader_1x05_P2.54mm_Vertical_SMD_Pin1Left

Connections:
+3V3: J1.3, U1.16 (3V3)
+5V: C1.1, R1.1, R2.1, U1.17 (VBUS), U4.5 (VCC)
/k44: SW1.S2, SW2.S2
ENA: SW1.A, SW2.A
ENB: SW1.B, SW2.B
GND: J1.4, K11.1, K12.1, K13.1, K14.1, K15.1, K21.1, K22.1, K23.1, K24.1, K25.1, K31.1, K32.1, K33.1, K34.1, K35.1, K41.1, K42.1, K43.1, R3.2, SW1.C, SW1.S1, SW2.C, SW2.S1, U1.19 (GND), U1.20 (GND), U4.4 (GND)
TP_CLK: R1.2, U4.3 (CLK)
TP_DAT: R2.2, U4.2 (DAT)
TP_RST: C1.2, R3.1, U4.1 (RST)

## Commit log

2022-12-03 feat: add kicad source files
    [smartkeeb.kicad_pcb, smartkeeb.kicad_sch]
2022-12-03 fix: rename files
    [pskeeb2.kicad_pcb, pskeeb2.kicad_sch]
2022-12-03 feat: finish design
    [pskeeb2.kicad_pcb, pskeeb2.kicad_sch]
2022-12-03 chore: export gerber
    [pskeeb2.kicad_pcb]
2022-12-07 feat: shipped to factory for the pilot
    [bottom-plate.dxf, pskeeb2.kicad_pcb, pskeeb2.kicad_sch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]
2022-12-08 fix: trrs tx did not connect
    [pskeeb2.kicad_pcb]
2023-01-01 fix: switch courtyard too small / trackpoint mounting
    [pskeeb2.kicad_pcb, pskeeb2.kicad_sch]
2023-01-09 feat: pskeeb2.1
    [bottom-plate.dxf, plates.dxf, pskeeb2.kicad_pcb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]
2023-01-25 fix: leave more space for soldering / use gh1.25 socket for trackpoint
    [pskeeb2.kicad_pcb, pskeeb2.kicad_sch]
2023-03-12 chore: rev 2.4
    [plates.dxf, pskeeb2.kicad_pcb, pskeeb2.kicad_sch]
2023-03-14 feat: releasing 2.5
    [plates.dxf, pskeeb2.5-case.stl, pskeeb2.5-topplate.dxf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]
2023-03-15 docs: update bom and trackpoint pinout
2023-09-24 feat: organize folders for new boards
    [pskeeb2-mx-bp.kicad_pcb, pskeeb2-mx-bp.kicad_sch, pskeeb2-mx-pico.kicad_pcb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]
2023-09-24 refactor: rename to shorter form
    [pskeeb2-ak-bp.kicad_pcb, pskeeb2-ak-bp.kicad_sch, pskeeb2-ak-pico.kicad_pcb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]
2023-10-04 feat: cherry hotswap shipped to jlc
    [bottom-plate-200x300x1mm-transparent.dxf, bottom-spacer-200x300x2mm-transparent.dxf, pskeeb2-ak-pico.kicad_pcb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]
2023-10-04 chore: update kwkb-kicad
2023-10-10 refactor: rename all designs for a cleaner convention
    [bottom-plate-200x300x1mm-transparent.dxf, bottom-spacer-200x300x2mm-transparent.dxf, plates-shield-cutting.FCStd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]
2023-10-19 fix: update plates
    [bottom-plate-200x300x1mm-transparent.dxf, bottom-spacer-200x300x2mm-transparent.dxf, pskeeb3_cherry_hotswap.kicad_pcb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]
2024-01-12 fix: update top plate cut
    [top-plate-200x300x2mm-blk.dxf]
2024-03-16 feat: added qrcode placeholder
    [bottom-plate-200x300x1mm-transparent.dxf, bottom-spacer-200x300x2mm-transparent.dxf, pskeeb3_cherry_hotswap.kicad_pcb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]
2024-08-29 feat: add pskeeb
    [pskeeb3_cherry_hotswap.kicad_pcb, pskeeb3_cherry_hotswap.kicad_sch, pskeeb4_gtr_lp_ks27_hotswap.kicad_pcb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]
2024-11-14 feat: added hugebug trackball
    [bom.csv, designators.csv, positions.csv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]
2025-01-10 refactor: increase footprint pads for easier soldering
    [pskeeb3_cherry_hotswap.kicad_pcb, pskeeb3_cherry_hotswap.kicad_sch, pskeeb4_gtr_lp_ks27_hotswap.kicad_pcb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]
2025-02-06 feat: added trackball ultimate_ergo
    [bom.csv, designators.csv, positions.csv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]
